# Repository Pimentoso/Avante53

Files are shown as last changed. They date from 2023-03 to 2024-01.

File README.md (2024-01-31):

# Avante53
Open-source 53 keys alice-style ortho keyboard. Features hotswap switches, a rotary encoder, and OLED screen.

## Bill of materials
- 53 Hotswap sockets
  - https://www.aliexpress.com/item/4001051840976.html
- 54 SMD 1N4148 diodes
  - https://www.aliexpress.com/item/32849879904.html
- Teensy 2.0 microcontroller
  - https://www.aliexpress.com/item/4000829915634.html
- a rotary encoder
  - https://www.aliexpress.com/item/10000056483250.html (the 15mm half handle)
- 11x 5mm m2 standoffs
  - https://www.aliexpress.com/item/1005004564012666.html
- 11x m2 nuts
- 11x short m2 screws (8-10mm)
- 53 switches of your choice
- any set of preonic/ortho keycaps
  - I used https://www.aliexpress.com/item/1005003294964787.html
- recommended: a 3d printer for the case and plate
- optional: 128x32 OLED screen breakout board
  - https://www.aliexpress.com/item/32850288143.html
- optional: a very short ws2812b led strip (like 5 leds)
  - https://www.aliexpress.com/item/2036819167.html

## Building
It's pretty straightforward.
- get the PCB printed at JLCPCB or your supplier of choice.
- solder the teensy on the underside with its header pins.
- solder the diodes and hotswap sockets.
- solder the encoder and oled screen on the top side of the board.
- print the case, and punch open the screw holes. If you printed the 2 separate pieces, put them on a flat surface like glass, and glue them together with super glue.
- push the nuts in the holes from the bottom, and screw in the standoffs.
- put the PCB in the case and screw it in.
- print the plate and install it along with the switches.
- done!

## Flashing
You can clone my fork of vial (https://github.com/Pimentoso/vial-qmk) and compile the keymap for this keyboard with `make pimentoso/avante53:vial`
Or you can just flash the compiled binary you can find in the `firmware` folder, using QMK toolbox or a tool of your choice.
Then you can use vial to edit the keymap.

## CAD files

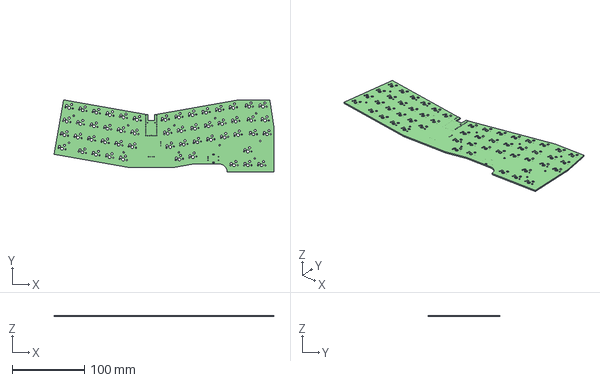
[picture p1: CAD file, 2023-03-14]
kicad/pcb/pcb.step
303.7 x 99.9 x 1.60 mm

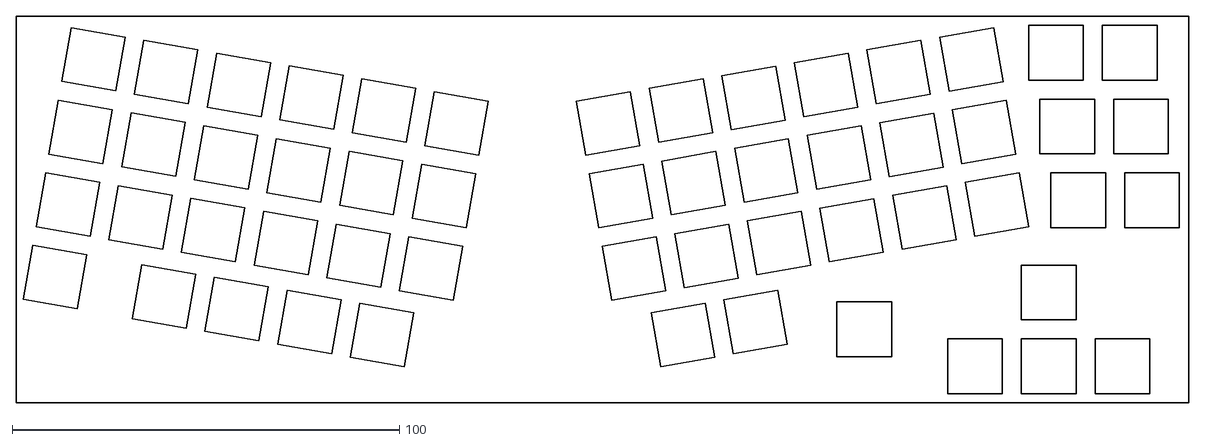
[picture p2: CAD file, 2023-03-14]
misc/plate/c2c223e2fd4069d25ad26155f856b8e2b4dcda65_switch.dxf
302.7 x 99.9

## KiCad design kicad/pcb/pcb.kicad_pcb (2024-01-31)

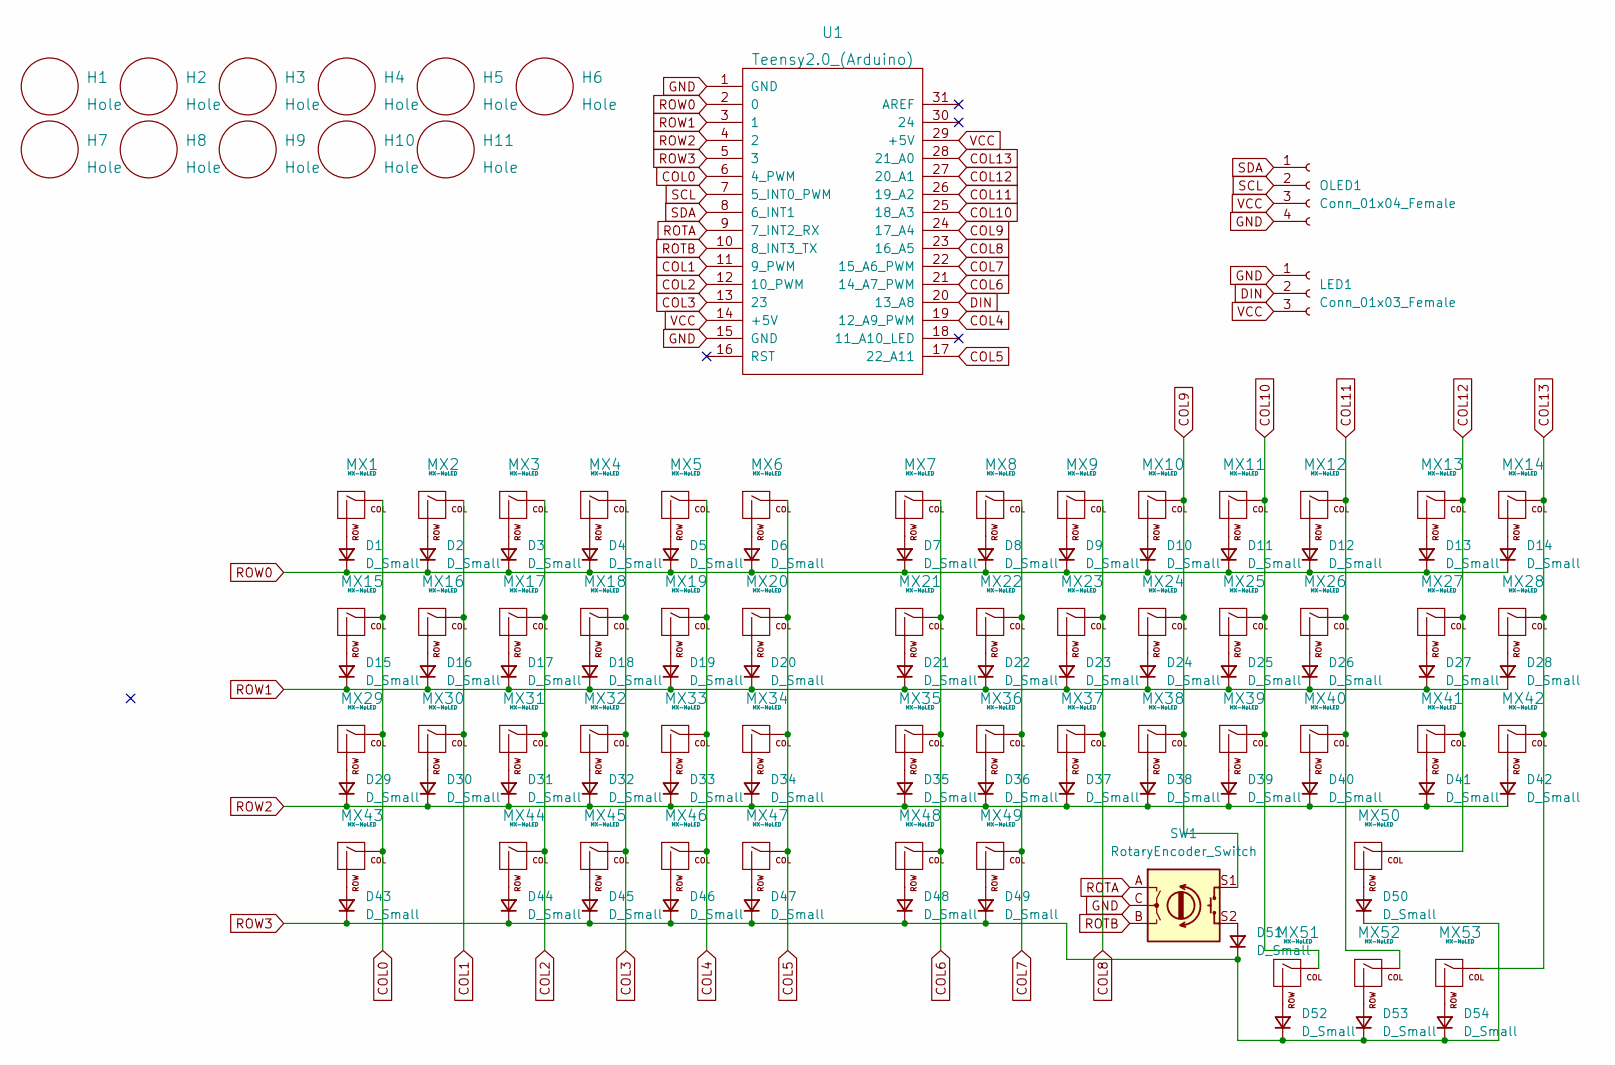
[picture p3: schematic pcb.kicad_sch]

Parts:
D1, D2, D3, D4, D5, D6, D7, D8, D9, D10, D11, D12, D13, D14, D15, D16, D17, D18, D19, D20, D21, D22, D23, D24, D25, D26, D27, D28, D29, D30, D31, D32, D33, D34, D35, D36, D37, D38, D39, D40, D41, D42, D43, D44, D45, D46, D47, D48, D49, D50, D51, D52, D53, D54: D_Small; D_MiniMELF
H1, H2, H3, H4, H5, H6, H7, H8, H9, H10, H11: Hole; MountingHole_2.2mm_M2_Pad_TopOnly
LED1: Conn_01x03_Female; PinHeader_1x03_P2.54mm_Vertical
MX1, MX2, MX3, MX4, MX5, MX6, MX7, MX8, MX9, MX10, MX11, MX12, MX13, MX14, MX15, MX16, MX17, MX18, MX19, MX20, MX21, MX22, MX23, MX24, MX25, MX26, MX27, MX28, MX29, MX30, MX31, MX32, MX33, MX34, MX35, MX36, MX37, MX38, MX39, MX40, MX41, MX42, MX43, MX44, MX45, MX46, MX47, MX48, MX49, MX50, MX51, MX52, MX53: MX-NoLED; MXOnly-1U-Hotswap
OLED1: Conn_01x04_Female; PinHeader_1x04_P2.54mm_Vertical
SW1: RotaryEncoder_Switch; RotaryEncoder_EC11
U1: Teensy2.0_(Arduino); Teensy_2.0

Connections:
COL0: MX1.1 (COL), MX15.1 (COL), MX29.1 (COL), MX43.1 (COL), U1.6 (4_PWM)
COL1: MX2.1 (COL), MX16.1 (COL), MX30.1 (COL), U1.11 (9_PWM)
COL2: MX3.1 (COL), MX17.1 (COL), MX31.1 (COL), MX44.1 (COL), U1.12 (10_PWM)
COL3: MX4.1 (COL), MX18.1 (COL), MX32.1 (COL), MX45.1 (COL), U1.13 (23)
COL4: MX5.1 (COL), MX19.1 (COL), MX33.1 (COL), MX46.1 (COL), U1.19 (12_A9_PWM)
COL5: MX6.1 (COL), MX20.1 (COL), MX34.1 (COL), MX47.1 (COL), U1.17 (22_A11)
COL6: MX7.1 (COL), MX21.1 (COL), MX35.1 (COL), MX48.1 (COL), U1.21 (14_A7_PWM)
COL7: MX8.1 (COL), MX22.1 (COL), MX36.1 (COL), MX49.1 (COL), U1.22 (15_A6_PWM)
COL8: MX9.1 (COL), MX23.1 (COL), MX37.1 (COL), U1.23 (16_A5)
COL9: MX10.1 (COL), MX24.1 (COL), MX38.1 (COL), SW1.S1, U1.24 (17_A4)
COL10: MX11.1 (COL), MX25.1 (COL), MX39.1 (COL), MX51.1 (COL), U1.25 (18_A3)
COL11: MX12.1 (COL), MX26.1 (COL), MX40.1 (COL), MX52.1 (COL), U1.26 (19_A2)
COL12: MX13.1 (COL), MX27.1 (COL), MX41.1 (COL), MX50.1 (COL), U1.27 (20_A1)
COL13: MX14.1 (COL), MX28.1 (COL), MX42.1 (COL), MX53.1 (COL), U1.28 (21_A0)
DIN: LED1.2, U1.20 (13_A8)
GND: LED1.1, OLED1.4, SW1.C, U1.1 (GND), U1.15 (GND)
unnamed: D1.2 (A), MX1.2 (ROW)
unnamed: D2.2 (A), MX2.2 (ROW)
unnamed: D3.2 (A), MX3.2 (ROW)
unnamed: D4.2 (A), MX4.2 (ROW)
unnamed: D5.2 (A), MX5.2 (ROW)
unnamed: D6.2 (A), MX6.2 (ROW)
unnamed: D7.2 (A), MX7.2 (ROW)
unnamed: D8.2 (A), MX8.2 (ROW)
unnamed: D9.2 (A), MX9.2 (ROW)
unnamed: D10.2 (A), MX10.2 (ROW)
unnamed: D11.2 (A), MX11.2 (ROW)
unnamed: D12.2 (A), MX12.2 (ROW)
unnamed: D13.2 (A), MX13.2 (ROW)
unnamed: D14.2 (A), MX14.2 (ROW)
unnamed: D15.2 (A), MX15.2 (ROW)
unnamed: D16.2 (A), MX16.2 (ROW)
unnamed: D17.2 (A), MX17.2 (ROW)
unnamed: D18.2 (A), MX18.2 (ROW)
unnamed: D19.2 (A), MX19.2 (ROW)
unnamed: D20.2 (A), MX20.2 (ROW)
unnamed: D21.2 (A), MX21.2 (ROW)
unnamed: D22.2 (A), MX22.2 (ROW)
unnamed: D23.2 (A), MX23.2 (ROW)
unnamed: D24.2 (A), MX24.2 (ROW)
unnamed: D25.2 (A), MX25.2 (ROW)
unnamed: D26.2 (A), MX26.2 (ROW)
unnamed: D27.2 (A), MX27.2 (ROW)
unnamed: D28.2 (A), MX28.2 (ROW)
unnamed: D29.2 (A), MX29.2 (ROW)
unnamed: D30.2 (A), MX30.2 (ROW)
unnamed: D31.2 (A), MX31.2 (ROW)
unnamed: D32.2 (A), MX32.2 (ROW)
unnamed: D33.2 (A), MX33.2 (ROW)
unnamed: D34.2 (A), MX34.2 (ROW)
unnamed: D35.2 (A), MX35.2 (ROW)
unnamed: D36.2 (A), MX36.2 (ROW)
unnamed: D37.2 (A), MX37.2 (ROW)
unnamed: D38.2 (A), MX38.2 (ROW)
unnamed: D39.2 (A), MX39.2 (ROW)
unnamed: D40.2 (A), MX40.2 (ROW)
unnamed: D41.2 (A), MX41.2 (ROW)
unnamed: D42.2 (A), MX42.2 (ROW)
unnamed: D43.2 (A), MX43.2 (ROW)
unnamed: D44.2 (A), MX44.2 (ROW)
unnamed: D45.2 (A), MX45.2 (ROW)
unnamed: D46.2 (A), MX46.2 (ROW)
unnamed: D47.2 (A), MX47.2 (ROW)
unnamed: D48.2 (A), MX48.2 (ROW)
unnamed: D49.2 (A), MX49.2 (ROW)
unnamed: D50.2 (A), MX50.2 (ROW)
unnamed: D51.2 (A), SW1.S2
unnamed: D52.2 (A), MX51.2 (ROW)
unnamed: D53.2 (A), MX52.2 (ROW)
unnamed: D54.2 (A), MX53.2 (ROW)
ROTA: SW1.A, U1.9 (7_INT2_RX)
ROTB: SW1.B, U1.10 (8_INT3_TX)
ROW0: D1.1 (K), D2.1 (K), D3.1 (K), D4.1 (K), D5.1 (K), D6.1 (K), D7.1 (K), D8.1 (K), D9.1 (K), D10.1 (K), D11.1 (K), D12.1 (K), D13.1 (K), D14.1 (K), U1.2 (0)
ROW1: D15.1 (K), D16.1 (K), D17.1 (K), D18.1 (K), D19.1 (K), D20.1 (K), D21.1 (K), D22.1 (K), D23.1 (K), D24.1 (K), D25.1 (K), D26.1 (K), D27.1 (K), D28.1 (K), U1.3 (1)
ROW2: D29.1 (K), D30.1 (K), D31.1 (K), D32.1 (K), D33.1 (K), D34.1 (K), D35.1 (K), D36.1 (K), D37.1 (K), D38.1 (K), D39.1 (K), D40.1 (K), D41.1 (K), D42.1 (K), U1.4 (2)
ROW3: D43.1 (K), D44.1 (K), D45.1 (K), D46.1 (K), D47.1 (K), D48.1 (K), D49.1 (K), D50.1 (K), D51.1 (K), D52.1 (K), D53.1 (K), D54.1 (K), U1.5 (3)
SCL: OLED1.2, U1.7 (5_INT0_PWM)
SDA: OLED1.1, U1.8 (6_INT1)
VCC: LED1.3, OLED1.3, U1.14 (+5V), U1.29 (+5V)

Board: 2 copper layers, 122 parts (1 on the bottom side), 79 nets, no tracks yet.
